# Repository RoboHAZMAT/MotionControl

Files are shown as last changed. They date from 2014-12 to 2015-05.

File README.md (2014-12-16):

Motion Control
=============

Code for the intuitive motion control for the robot. This repo contains all of the code needed to use the wearable motion control interface. Main features are the Motion Control Glove code and the IMU sensor reading programs.

###**Directories:**

  - **HandMotionControlOpt:** An optimized version of the code needed to operate the robot hands using the flex sensor based gloves. Takes the voltage drop readings from the flex sensor in the analog pins and relates that to servo motor rotation angles. Has a calibration method for different sized hands with a default setting as well. Green, yellow, and red LED status lights are used. Written for an Arduino Lilypad.

  - **IMUReading:** Contains several library files developed by Jeff Rowberg to deal with reading in the MPU 9150 IMU sensor we are using as well as the DMP. Two versions of IMU reading programs are functional, one which uses the DMP and one that uses the raw gyroscope and accelerometer data along with our custom Kalman Filter.
  
  - **Kalman Filter MATLAB:** Old code written for Dr. Tomonari Furukawa's Bayesian Robotics course implementing a one DOF Kalman Filter for accurate yaw estimates and drift cancelling.
  
  - **Mechtronic Arm:** In progress directory for controlling the Mechatronic Arm in various ways for testing.
  
  - **Tactile Feedback:** In progress directory used for tactile feedback code. The plan is to use a pressure sensor at the tips of the gripper fingers that senses when the gripper is touching an object. The pressure is related so some sort of tactile feedback method, either small inflatable pressure bags on the glove fingers or small vibration motors. 
  
  - **I2CDev:** Added standard library for communication over I2C on Arduino.

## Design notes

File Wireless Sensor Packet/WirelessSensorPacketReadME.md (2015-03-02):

#Wireless Sensor Packets
In an effort to alleviate cumbersome wires, we are attempting to use the Nordic SemiCondutor nRF24l01+ modules for 2.4Ghz datatransfer. Using the Rf24 library from maniacbug, we communicate with the nRF24l01+ and can send data at rates of up to 2Mbps. SPI protocol is used to configure and communicate with the transceivers. The ultimate goal of this is to have several Wireless Sensor Packets that communicate with IMUs and flex sensors that communicate in a star formation back to a main base node and feed the sensor information into the main Matlab program.

###Wireless Sensor Packet (proposed) Component List
* [Arduino Pro Mini (3.3V, 8MHz) w/ ATMega328] (https://www.sparkfun.com/products/11114)
* [Sparkfun MPU-9150 Breakout Board] (https://www.sparkfun.com/products/11486)
* [Nordic SemiConductor nRF24l01+] (http://www.amazon.com/gp/product/B00E594ZX0/ref=oh_aui_detailpage_o09_s00?ie=UTF8&psc=1) 
* [Polymer Lithium Ion Battery (1000mAh ~ 2000mAh)] (https://www.sparkfun.com/products/339)
* [SparkFun LiPo Charger Basic - Micro-USB] (https://www.sparkfun.com/products/10217)
* [Sparkfun Flex Sensor 4.5"] (https://www.sparkfun.com/products/8606)
* [Button] (https://www.sparkfun.com/products/97)
* [LEDs] (http://www.opel.ece.vt.edu/reference/DataSheets/08LCHR10-LED.pdf)
* [Perfboard] (http://www.dx.com/p/electrical-bakelite-circuit-board-5x7cm-10-piece-132480#.VOuZ5_nF_qs)
* [Switch] (http://www.elexp.com/ProductDetails.aspx?item_no=17SLDH251&CatId=36e69afb-3c1f-4322-9ac3-6e126246b7ae)

#####Variations
There will be two different sensor packets that only vary slightly. Cases are being designed to be 3D printed for each packet set. The packet mounted on the wrist will handle the flex sensor used for actuating the gripper of the robot. This sensors packet will also include 3-4 LEDs. The sensor packet mounted on the bicep of the operator will only have 1-2 LEDs and no flex sensor.

###Testing
To learn how to use the RF24 library, we found an example of a star formation called [starping.pde] (http://maniacbug.github.io/RF24/starping_8pde-example.html) (we copied this into an .ino file). In this setup, the same code can be written to each Arduino participating in the network. The role of the arduino is determined by the status of pin 7. If the value of pin 7 is connected to GND, the arduino behaves as a "pong out" node, which recieves the incoming signals and sends it back to the sender. All other Arduinos behave as "ping" modules which initiate the signal. Each ping module needs an ID. This can be set up in the serial monitor of the Arduino IDE. ID's 2-6 are available to the ping modules, while ID 1 is reserved for the pong back module. An ID of 0 indicates that no ID has been assigned to the node. Once IDs are assigned for a ping module, they are stored in the EEPROM of the Arduino, so they will remain until changed. Slight modification of the starping code is needed for operation on an Arduino Mega due to the specific pin callouts of the SPI functionality on the Mega. Specifically, pin 10 on the Arduino Uno and Pro Mini needs to be changed to pin 53 on the Mega. More information on the setup of the nRF24l01+ can be found on [this website] (http://arduino-info.wikispaces.com/Nrf24L01-2.4GHz-HowTo). It is advisable to solder a 10microF or greater electrolytic capacitor across the VCC and GND pins on the nRF24l01 board, especially when using the Mega. This is due to some issue with the power supplied by the Mega which causes rampant packet loss on the nRF24l01+.

We needed to send data structures instead of just integers like in the starping example. [This example] (http://www.bajdi.com/sending-structs-with-nrf24l01-modules-and-the-rf24-library/) has constructed data structures consisting of both integers and floats. We are combining these examples and mixing in our own code.

###Implementation
We have confirmed the basic example of the starping setup. We successfully sent the IMU data structure (plus more) wirelessly via the Arduino Nano to an Arduino Mega. We are now moving forward with the WSP module (i.e. the housing that will be worn by an operator). An integrated PCB version of the WSP is being worked on which will reduce the size and weight of the WSP.

###PCB Design & Destruction
The PCB we are designing will integrate the major components of the board. The nRF24l01 will remain a separete piece to be soldered into the main board. The breakout boards that we are using are all from Sparkfun. The schematics can be found for each breakout board. We are taking these existing EAGLE schematics and integrating them into one board. In addition to these boards, we need to integrate two LEDs, a slide switch, pin breakouts to connect the nRF24l01, breakout pins for the flex sensor, and a button. There will also need to be debug pads to check voltages on various parts of the board. IMPORTANT: Bootload pins will be needed for the ATMEGA328. [This is a 6-pin configuration TBD] (http://angryelectron.com/how-to-update-the-bootloader-on-arduino-pro-mini-328/). The current iteration is called WSP2.sch. It is still in part selection and integration phase. Schematic integration is almost complete. Breakout pins/debug pads need to be determined. The LEDS and button still need to be connected. Once this is complete, the board needs to be create. It is important that the various pieces be oriented correctly. The MPU 9150 needs to be as close to the edge of the PCB as possible (preferably about 1/4th of the way up the board). This is because the MPU needs to be close to where the wrist will be when worn by an operator. The (indicator) LEDS, button and switch ideally need to be very close to each other to make the controls available on top of the Wireless Sensor packet available,

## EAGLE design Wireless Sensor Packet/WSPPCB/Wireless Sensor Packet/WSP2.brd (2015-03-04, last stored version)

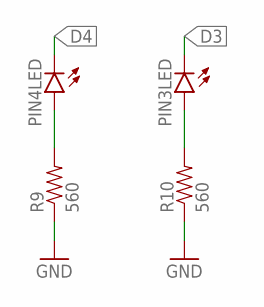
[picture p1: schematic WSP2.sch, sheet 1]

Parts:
PIN3LED, PIN4LED: LED0603; LED-0603
R9, R10: 560; 0603-RES

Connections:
D3: PIN3LED.C; also elsewhere on the board
D4: PIN4LED.C; also elsewhere on the board
GND: R9.1, R10.1; also elsewhere on the board
unnamed: PIN4LED.A, R9.2
unnamed: PIN3LED.A, R10.2

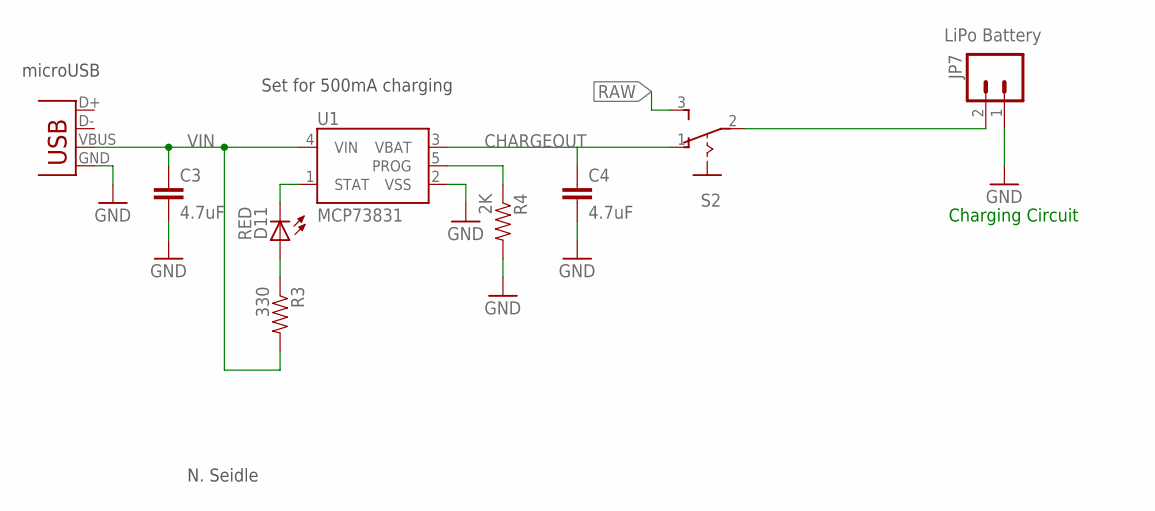
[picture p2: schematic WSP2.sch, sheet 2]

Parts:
C3, C4: 4.7uF; 0402-CAP
D11: RED; LED-0603
JP7: LiPo Battery; JST-2-SMD
R3: 330; 0402-RES
R4: 2K; 0402-RES
S2: 255SB
U1: MCP73831; SOT23-5
X1: Micro USB; USB-MICROB

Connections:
CHARGEOUT: C4.1, S2.1 (O), U1.3 (VBAT)
GND: C3.2, C4.2, JP7.1, R4.2, U1.2 (VSS), X1.GND; also elsewhere on the board
unnamed: D11.A, R3.1
POSBAT: JP7.2, S2.2
PROG: R4.1, U1.5 (PROG)
RAW: S2.3 (S); also elsewhere on the board
STAT: D11.C, U1.1 (STAT)
VIN: C3.1, R3.2, U1.4 (VIN), X1.VBUS

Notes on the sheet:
Set for 500mA charging
N. Seidle
microUSB
Charging Circuit

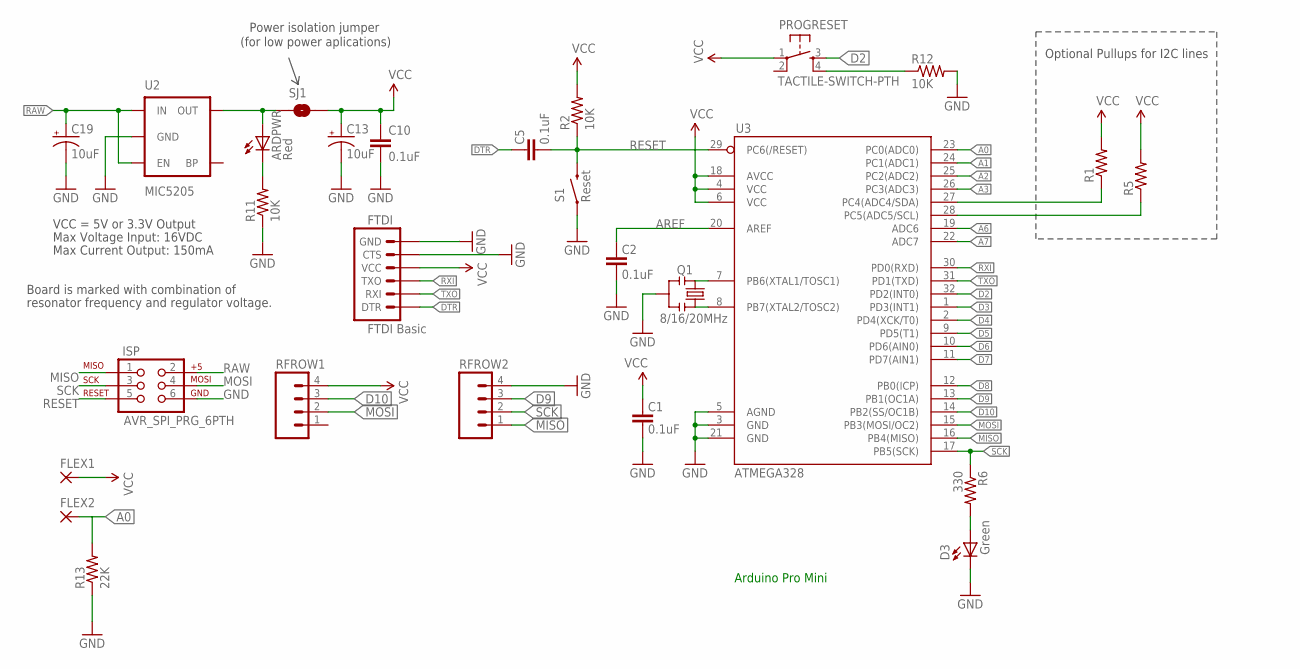
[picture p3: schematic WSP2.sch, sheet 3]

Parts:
ARDPWR: Red; 0603-LED-ALT1
C1, C2, C5, C10: 0.1uF; 0603-CAP
C13, C19: 10uF; EIA3216
D3: Green; 0603-LED-ALT1
FLEX1, FLEX2: 1,6/0,9
FTDI: FTDI Basic; 1X06
ISP: AVR_SPI_PRG_6PTH; 2X3
PROGRESET: TACTILE-SWITCH-PTH; TAC-SWITCH-PTH
Q1: 8/16/20MHz; RESONATOR-SMD-1:1
R1, R5: RESISTOR0603-RES; 0603-RES
R2, R11, R12: 10K; 0603-RES
R6: 330; 0603-RES
R13: 22K; 0603-RES
RFROW1, RFROW2: M041.27MM; 1X04-1.27MM
S1: Reset; TACTILE-SWITCH-SMD-ALT01
SJ1: SOLDERJUMPERNC; SJ_2S
U2: MIC5205; SOT23-5
U3: ATMEGA328; TQFP32-08

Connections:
3.3V: FLEX1.1, FTDI.4 (VCC), PROGRESET.1, RFROW1.4
A0: FLEX2.1, R13.2, U3.23 (PC0(ADC0))
A1: U3.24 (PC1(ADC1))
A2: U3.25 (PC2(ADC2))
A3: U3.26 (PC3(ADC3))
A5: R5.1, U3.28 (PC5(ADC5/SCL))
A6: U3.19 (ADC6)
A7: U3.22 (ADC7)
AREF: C2.2, U3.20 (AREF)
D2: PROGRESET.3, U3.32 (PD2(INT0))
D3: U3.1 (PD3(INT1)); also elsewhere on the board
D4: U3.2 (PD4(XCK/T0)); also elsewhere on the board
D5: U3.9 (PD5(T1))
D6: U3.10 (PD6(AIN0))
D7: U3.11 (PD7(AIN1))
D8: U3.12 (PB0(ICP))
D9: RFROW2.3, U3.13 (PB1(OC1A))
D10: RFROW1.3, U3.14 (PB2(SS/OC1B))
DTR: C5.2, FTDI.1 (DTR)
GND: C1.1, C2.1, C10.2, C13.C (-), C19.C (-), D3.C, FTDI.5 (CTS), FTDI.6 (GND), ISP.6, Q1.2, R11.1, R12.2, R13.1, RFROW2.4, S1.1, S1.2 (1), U2.2 (GND), U3.3 (GND), U3.5 (AGND), U3.21 (GND); also elsewhere on the board
MISO: ISP.1, RFROW2.1, U3.16 (PB4(MISO))
MOSI: ISP.4, RFROW1.2, U3.15 (PB3(MOSI/OC2))
unnamed: Q1.3, U3.8 (PB7(XTAL2/TOSC2))
unnamed: Q1.1, U3.7 (PB6(XTAL1/TOSC1))
unnamed: ARDPWR.A, SJ1.1, U2.5 (OUT)
unnamed: ARDPWR.C, R11.2
unnamed: D3.A, R6.2
unnamed: PROGRESET.4, R12.1
RAW: C19.A (+), ISP.2, U2.1 (IN), U2.3 (EN); also elsewhere on the board
RESET: C5.1, ISP.5, R2.1, S1.3 (2), S1.4 (2), U3.29 (PC6(/RESET))
RXI: FTDI.3 (TXO), U3.30 (PD0(RXD))
SCK: ISP.3, R6.1, RFROW2.2, U3.17 (PB5(SCK))
SDA: R1.1, U3.27 (PC4(ADC4/SDA)); also elsewhere on the board
TXO: FTDI.2 (RXI), U3.31 (PD1(TXD))
VCC: C1.2, C10.1, C13.A (+), R1.2, R2.2, R5.2, SJ1.2, U3.4 (VCC), U3.6 (VCC), U3.18 (AVCC); also elsewhere on the board

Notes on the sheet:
Max Voltage Input: 16VDC
Max Current Output: 150mA
Board is marked with combination of
resonator frequency and regulator voltage.
VCC = 5V or 3.3V Output
Optional Pullups for I2C lines
Power isolation jumper
(for low power aplications)
Arduino Pro Mini

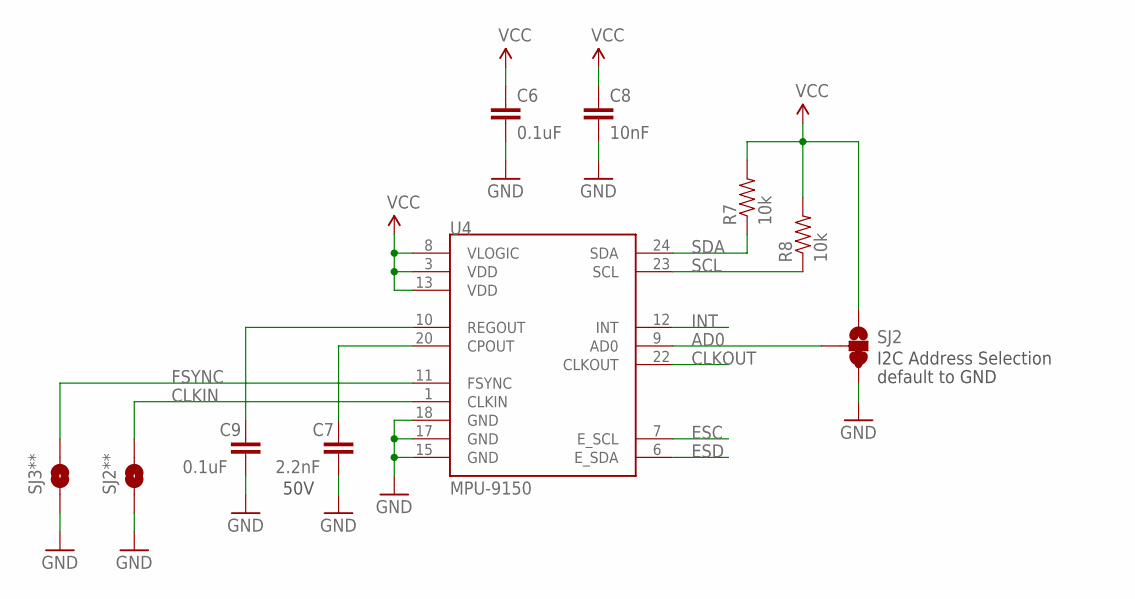
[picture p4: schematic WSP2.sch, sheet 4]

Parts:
C6, C9: 0.1uF; 0402-CAP
C7: 2.2nF; 0402-CAP
C8: 10nF; 0402-CAP
R7, R8: 10k; 0402-RES
SJ2: SOLDERJUMPER_2WAYPASTE2&3; SJ_3_PASTE2&3
SJ2**, SJ3**: SOLDERJUMPERTRACE; SJ_2S-TRACE
U4: MPU-9150; QFN-24-NP

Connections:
AD0: SJ2.2, U4.9 (AD0)
CLKIN: SJ2**.2, U4.1 (CLKIN)
CLKOUT: U4.22 (CLKOUT)
ESC: U4.7 (E_SCL)
ESD: U4.6 (E_SDA)
FSYNC: SJ3**.2, U4.11 (FSYNC)
GND: C6.2, C7.2, C8.2, C9.2, SJ2.3, SJ2**.1, SJ3**.1, U4.15 (GND), U4.17 (GND), U4.18 (GND); also elsewhere on the board
INT: U4.12 (INT)
unnamed: C7.1, U4.20 (CPOUT)
unnamed: C9.1, U4.10 (REGOUT)
SCL: R8.1, U4.23 (SCL)
SDA: R7.1, U4.24 (SDA); also elsewhere on the board
VCC: C6.1, C8.1, R7.2, R8.2, SJ2.1, U4.3 (VDD), U4.8 (VLOGIC), U4.13 (VDD); also elsewhere on the board

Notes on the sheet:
50V
I2C Address Selection
default to GND

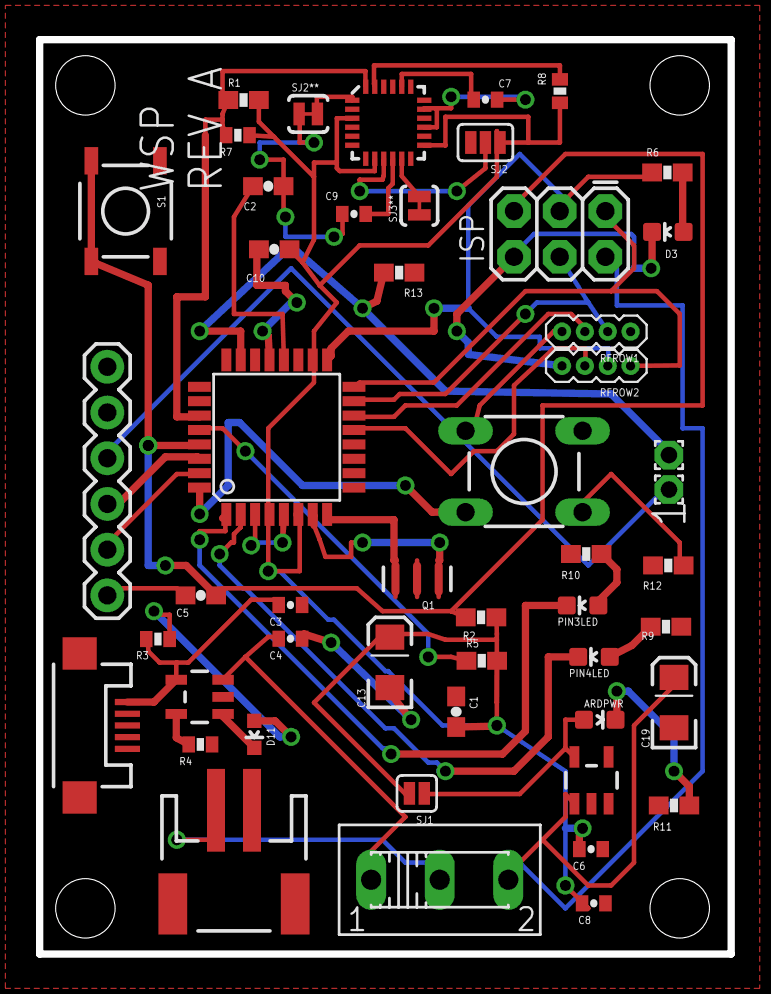
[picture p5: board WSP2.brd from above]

Board: 2 copper layers, 38.4 x 50.8 mm, 54 parts (0 on the bottom side), 40 nets.

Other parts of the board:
JP1, JP2, JP14, JP15: STAND-OFF

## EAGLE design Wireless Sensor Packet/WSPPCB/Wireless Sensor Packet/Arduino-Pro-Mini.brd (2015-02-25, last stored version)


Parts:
C1, C2, C3, C10: 0.1uF; 0603-CAP
C13, C19: 10uF; EIA3216
D3: Green; 0603-LED-ALT1
FRAME1: FRAME-LETTER; CREATIVE_COMMONS
JP1: FTDI Basic; 1X06
JP2, JP3: M02PTH; 1X02
JP5, JP8: FIDUCIALUFIDUCIAL; MICRO-FIDUCIAL
JP6, JP7: M12PTH; 1X12
LED1: Red; 0603-LED-ALT1
Q1: 8/16/20MHz; RESONATOR-SMD-1:1
R1, R3: RESISTOR0603-RES; 0603-RES
R2, R11: 10K; 0603-RES
R6: 330; 0603-RES
S1: Reset; TACTILE-SWITCH-SMD-ALT01
SJ1: SOLDERJUMPERNC; SJ_2S
U1: ATMEGA328; TQFP32-08
U2: MIC5205; SOT23-5
U$1: LOGO-SFESK; SFE-LOGO-FLAME
U$3: OSHW-LOGOS; OSHW-LOGO-S
U$11: LOGO-SFENEW; SFE-NEW-WEBLOGO

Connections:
A0: JP6.8, U1.23 (PC0(ADC0))
A1: JP6.7, U1.24 (PC1(ADC1))
A2: JP6.6, U1.25 (PC2(ADC2))
A3: JP6.5, U1.26 (PC3(ADC3))
A4: JP2.1, R1.1, U1.27 (PC4(ADC4/SDA))
A5: JP2.2, R3.1, U1.28 (PC5(ADC5/SCL))
A6: JP3.1, U1.19 (ADC6)
A7: JP3.2, U1.22 (ADC7)
AREF: C1.2, U1.20 (AREF)
D2: JP7.8, U1.32 (PD2(INT0))
D3: JP7.7, U1.1 (PD3(INT1))
D4: JP7.6, U1.2 (PD4(XCK/T0))
D5: JP7.5, U1.9 (PD5(T1))
D6: JP7.4, U1.10 (PD6(AIN0))
D7: JP7.3, U1.11 (PD7(AIN1))
D8: JP7.2, U1.12 (PB0(ICP))
D9: JP7.1, U1.13 (PB1(OC1A))
D10: JP6.12, U1.14 (PB2(SS/OC1B))
DTR: C2.2, JP1.1 (DTR)
GND: C1.1, C3.1, C10.2, C13.C (-), C19.C (-), D3.C, JP1.5 (CTS), JP1.6 (GND), JP6.2, JP7.9, Q1.2, R11.1, S1.1, S1.2 (1), U1.3 (GND), U1.5 (AGND), U1.21 (GND), U2.2 (GND)
MISO: JP6.10, U1.16 (PB4(MISO))
MOSI: JP6.11, U1.15 (PB3(MOSI/OC2))
unnamed: Q1.3, U1.8 (PB7(XTAL2/TOSC2))
unnamed: Q1.1, U1.7 (PB6(XTAL1/TOSC1))
unnamed: LED1.A, SJ1.1, U2.5 (OUT)
unnamed: LED1.C, R11.2
unnamed: D3.A, R6.2
RAW: C19.A (+), JP6.1, U2.1 (IN), U2.3 (EN)
RESET: C2.1, JP6.3, JP7.10, R2.1, S1.3 (2), S1.4 (2), U1.29 (PC6(/RESET))
RXI: JP1.3 (TXO), JP7.11, U1.30 (PD0(RXD))
SCK: JP6.9, R6.1, U1.17 (PB5(SCK))
TXO: JP1.2 (RXI), JP7.12, U1.31 (PD1(TXD))
VCC: C3.2, C10.1, C13.A (+), JP1.4 (VCC), JP6.4, R1.2, R2.2, R3.2, SJ1.2, U1.4 (VCC), U1.6 (VCC), U1.18 (AVCC)

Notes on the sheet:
Original Arduino Mini Design by Team Arduino
Arduino Pro Mini Design by Spark Fun Electronics
Max Voltage Input: 16VDC
Max Current Output: 150mA
Board is marked with combination of
resonator frequency and regulator voltage.
VCC = 5V or 3.3V Output
Optional Pullups for I2C lines
Off Grid Breakout headers
Power isolation jumper
(for low power aplications)

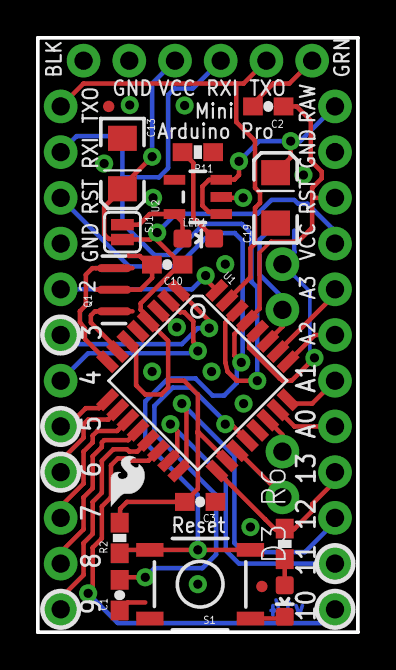
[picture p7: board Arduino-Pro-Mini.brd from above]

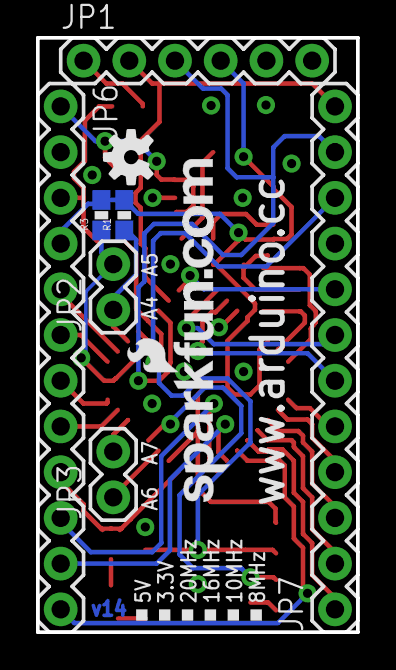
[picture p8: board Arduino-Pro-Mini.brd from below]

Board: 2 copper layers, 17.8 x 33.0 mm, 29 parts (9 on the bottom side), 33 nets.

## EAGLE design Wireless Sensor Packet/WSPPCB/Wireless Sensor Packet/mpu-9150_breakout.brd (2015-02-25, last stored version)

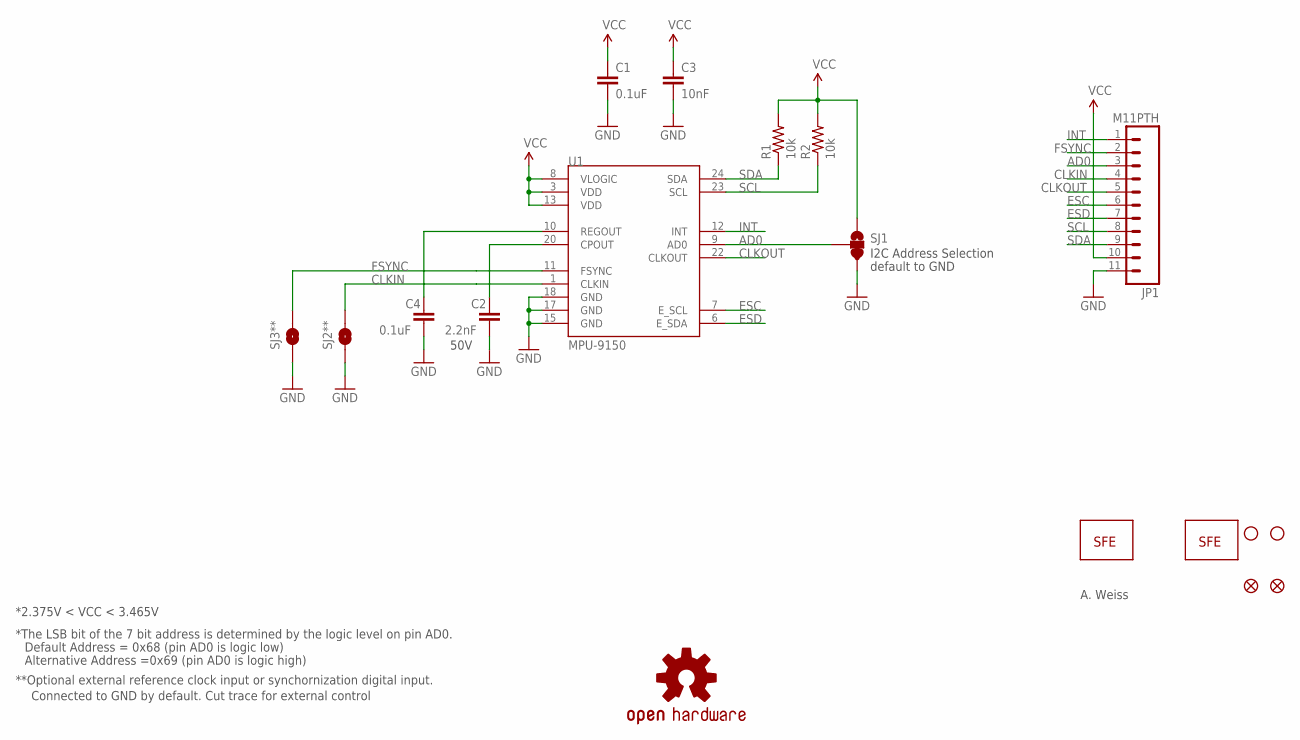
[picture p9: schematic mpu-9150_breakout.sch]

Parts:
C1, C4: 0.1uF; 0402-CAP
C2: 2.2nF; 0402-CAP
C3: 10nF; 0402-CAP
JP1: M11PTH; 1X11
JP2, JP3: STAND-OFF
JP4: LOGO-SFENW2; SFE-NEW-WEB
JP6: LOGO-SFESK; SFE-LOGO-FLAME
JP7, JP8: FIDUCIALUFIDUCIAL; MICRO-FIDUCIAL
R1, R2: 10k; 0402-RES
SJ1: SOLDERJUMPER_2WAYPASTE2&3; SJ_3_PASTE2&3
SJ2**, SJ3**: SOLDERJUMPERTRACE; SJ_2S-TRACE
U1: MPU-9150; QFN-24-NP
U$1: OSHW-LOGOS; OSHW-LOGO-S

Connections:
AD0: JP1.3, SJ1.2, U1.9 (AD0)
CLKIN: JP1.4, SJ2**.2, U1.1 (CLKIN)
CLKOUT: JP1.5, U1.22 (CLKOUT)
ESC: JP1.6, U1.7 (E_SCL)
ESD: JP1.7, U1.6 (E_SDA)
FSYNC: JP1.2, SJ3**.2, U1.11 (FSYNC)
GND: C1.2, C2.2, C3.2, C4.2, JP1.11, SJ1.3, SJ2**.1, SJ3**.1, U1.15 (GND), U1.17 (GND), U1.18 (GND)
INT: JP1.1, U1.12 (INT)
unnamed: C2.1, U1.20 (CPOUT)
unnamed: C4.1, U1.10 (REGOUT)
SCL: JP1.8, R2.1, U1.23 (SCL)
SDA: JP1.9, R1.1, U1.24 (SDA)
VCC: C1.1, C3.1, JP1.10, R1.2, R2.2, SJ1.1, U1.3 (VDD), U1.8 (VLOGIC), U1.13 (VDD)

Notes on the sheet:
50V
I2C Address Selection
**Optional external reference clock input or synchornization digital input.
Connected to GND by default. Cut trace for external control
Default Address = 0x68 (pin AD0 is logic low)
Alternative Address =0x69 (pin AD0 is logic high)
*The LSB bit of the 7 bit address is determined by the logic level on pin AD0.
default to GND
A. Weiss
*2.375V < VCC < 3.465V

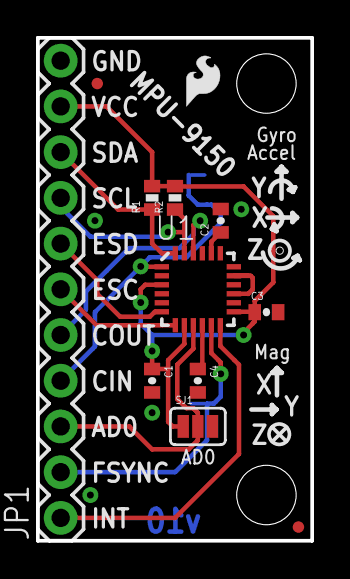
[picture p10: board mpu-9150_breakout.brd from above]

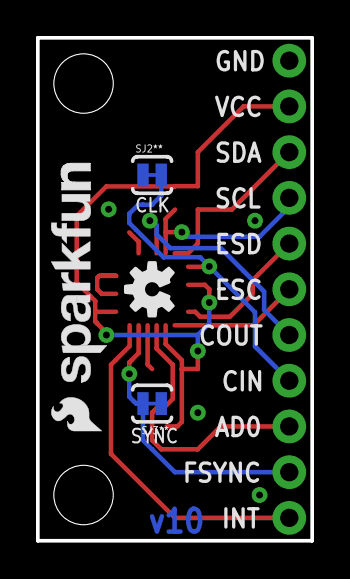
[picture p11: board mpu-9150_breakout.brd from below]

Board: 2 copper layers, 15.2 x 27.9 mm, 19 parts (5 on the bottom side), 13 nets.

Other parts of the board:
JP5: LOGO-SFESK; SFE-LOGO-FLAME

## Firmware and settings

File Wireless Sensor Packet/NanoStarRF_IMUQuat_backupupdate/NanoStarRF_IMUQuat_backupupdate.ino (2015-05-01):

  // ########## Wireless Sensor Packet ##########
/*
John Gardiner & Gerardo Bledt for the 2014-2015 Virginia Tech Mechanical
Engineering Senior Design RoboHazMat Project.
 */

// #### Libraries ####
//From Starping
#include <SPI.h>
#include <EEPROM.h>
#include "nRF24L01.h"
#include "RF24.h"
#include "printf.h"

//from IMU Quat
#include "Wire.h"
#include "I2Cdev.h"
#include "MPU6050_6Axis_MotionApps20.h"

// Set up nRF24L01 radio on SPI bus plus pins 9 & 10
RF24 radio(9,10);

// Instantiate arrays with comm pipes
//const uint64_t talking_pipes[5] = { 0xABCDABCD71LL, 0xF0F0F0F0C3LL, 0xF0F0F0F0B4LL, 0xF0F0F0F0A5LL, 0xF0F0F0F096LL };
//const uint64_t listening_pipes[5] = { 0xABCDABCD71LL, 0x3A3A3A3AC3LL, 0x3A3A3A3AB4LL, 0x3A3A3A3AA5LL, 0x3A3A3A3A96LL };

const uint64_t talking_pipes[5] = { 0xF0F0F0F0D2LL, 0xF0F0F0F0C3LL, 0xF0F0F0F0B4LL, 0xF0F0F0F0A5LL, 0xF0F0F0F096LL };
const uint64_t listening_pipes[5] = { 0x3A3A3A3AD2LL, 0x3A3A3A3AC3LL, 0x3A3A3A3AB4LL, 0x3A3A3A3AA5LL, 0x3A3A3A3A96LL };

// Where in EEPROM is the address stored?
const uint8_t address_at_eeprom_location = 0;

// What is our address (SRAM cache of the address from EEPROM)
// Note that zero is an INVALID address.  The pong back unit takes address
// 1, and the rest are 2-6
uint8_t node_address; //Set the WSP ID Here

// #### Structures ####
// In the future, verification characters need to be added to ensure
// that, even with packet loss, the right numbers are being sent to 
// the right channels.

// Wireless Packet Structure - quaternion and flex sensor
// Since the biceps do not have flex sensors, the will send a 
// specified null value

typedef struct{
  int N; //Sender ID
  float W;// quaternion begin
  float X;
  float Y;
  float Z;// quaternion end
  int F;// Flex sensor
  int reset;
  int T; //Time sent
}
A_t;

//variable declarations
A_t wirelesspacket;

//LEDs
int redled = 6;
int greenled = 7;
int blueled = 8;

//int reset = 0;

//IMU Quat stuff
//============================ Parameter Setup =============================
/* Defines and initializes the MPU9150 IMU sensor, the quaternion object, 
 * the reset button pins, and the MPU control/status variables and buffers.
 */
 
// MPU objeject with 0x68 default I2C address
MPU6050 mpu;

// Initialize Quaternion
Quaternion q;           // [w, x, y, z]

// Reset button pins
const int pinOut = 4; //JRG - Had to change to 1 & 2, 11&13 used by SPI
const int pinIn = 5;

// MPU control / status variables
bool dmpReady = false;  // set true if DMP init was successful
uint8_t devStatus;      // return status after each device operation (0 = success, !0 = error)
uint16_t packetSize;    // expected DMP packet size (default is 42 bytes)
uint16_t fifoCount;     // count of all bytes currently in FIFO
uint8_t fifoBuffer[64]; // FIFO storage buffer

// Flex Sensor Stuff
// Filtering constant 
const int numReadings = 10;
int sensorPin = A0;
int sensorValue = 0;
int maxR;
int minR;
int readingBuffer[numReadings];
int motorPos;
int i = 0;

void setup(void)
{
  // LEDs
  pinMode(6, OUTPUT); //Red
  pinMode(7, OUTPUT); //Green
  pinMode(8, OUTPUT); //Blue

  // Wireless Setup //
  // Read the address from EEPROM
    uint8_t reading = EEPROM.read(address_at_eeprom_location);

    // If it is in a valid range for node addresses, it is the address.
    if ( reading >= 2 && reading <= 6 )
      node_address = reading;

    // Otherwise, it is invalid, so set our address to 0. Readings cannot be sent.
    else
    {
      node_address = 0;
    }

  // Print information
  Serial.begin(115200);
  Serial.print("This is a Wireless Sensor Packet. It's address is: ");
  Serial.println(node_address);

  // Setup and configure rf radio
  radio.begin();
  radio.setDataRate(RF24_2MBPS); // Both endpoints must have this set the same
  radio.setAutoAck(false);       // Either endpoint can set to false to disable ACKs

  // Write on our talking pipe
  radio.openWritingPipe(talking_pipes[node_address-2]);
  // Listen on our listening pipe
  radio.openReadingPipe(1,listening_pipes[node_address-2]);
  
  // Show the details of the radio
  printf_begin();
  radio.printDetails();
  
  //Initializing values - will be sent as confirmation
  wirelesspacket.N = node_address;
  wirelesspacket.W = 1;
  wirelesspacket.X = 2;
  wirelesspacket.Y = 3;
  wirelesspacket.Z = 4;
  wirelesspacket.F = 5;
  
  // ##### IMU Quat #####
  // Begin I2C communication
  Wire.begin();
  
  // Initialize reset button
  //pinMode(pinOut, OUTPUT);
  pinMode(pinIn, INPUT);
  digitalWrite(pinOut, HIGH);

  // Initialize IMU
  Serial.println(F("Initializing I2C devices..."));
  mpu.initialize();
  digitalWrite(redled, HIGH);

  // Load and configure the DMP
  Serial.println(F("Initializing DMP..."));
  devStatus = mpu.dmpInitialize();
  digitalWrite(redled, LOW);
  delay(10);
  //digitalWrite(8, HIGH);
  analogWrite(blueled,220);
  
  // Make sure it worked (returns 0 if so)
  if (devStatus == 0) {
      // Turn on the DMP, now that it's ready
      Serial.println(F("Enabling DMP..."));
      mpu.setDMPEnabled(true);

      // Set our DMP Ready flag so the main loop() function knows it's okay to use it
      dmpReady = true;

      // Get expected DMP packet size for later comparison
      packetSize = mpu.dmpGetFIFOPacketSize();
      
  } else {
      // ERROR!
  }
  // Send confirmation of IMU initialization
  Serial.println("Sending setup confirmation...");
  radio.write( &wirelesspacket, sizeof(wirelesspacket) );
  Serial.println("Sent");
  //digitalWrite(8, LOW);
  analogWrite(blueled,150);
  delay(10);
  //digitalWrite(7, HIGH);
  analogWrite(greenled,150);
  
  //Set Up Flex Sensor Stuff
  maxR = 450;
  minR = 200;
  
  for (int j = 0; j < numReadings; j++) 
  {
    readingBuffer[j] = 0;
  }
  
}

void loop(void)
{
  //Flex Sensors
  int reading;
  reading = constrain(map(analogRead(sensorPin),minR,maxR,175,0),0,175);
  //Serial.println(analogRead(sensorPin)); 
  motorPos = MoveMotor(i,reading,readingBuffer,motorPos);
  //\Serial.println(motorPos);
  
  // IMU Communication // 
  // Resets length
  while (fifoCount < packetSize) fifoCount = mpu.getFIFOCount();
  //Serial.print("FIFO Count Over | ");Serial.println(millis());
  // Get current FIFO count
  fifoCount = mpu.getFIFOCount();

  // Check for overflow (this should never happen unless our code is too inefficient)
  if (fifoCount >= 1024) {
      // Reset so we can continue cleanly
      mpu.resetFIFO();
      //Serial.print("FIFO Reset | ");Serial.println(millis());
  } 
  
  //Serial.print("Start Wait | ");Serial.println(millis());
  // Wait for correct available data length, should be a VERY short wait
  while (fifoCount < packetSize) fifoCount = mpu.getFIFOCount();
  //Serial.print("Finish Wait | ");Serial.println(millis());

  // Read a packet from FIFO
  mpu.getFIFOBytes(fifoBuffer, packetSize);
  //Serial.print("Packet Read | ");Serial.println(millis());
       
  // Track FIFO count here in case there is > 1 packet available
  // (this lets us immediately read more without waiting for an interrupt)
  fifoCount -= packetSize;

  // Display quaternion values in easy matrix form: w x y z
  mpu.dmpGetQuaternion(&q, fifoBuffer);
  //Serial.print("Got Quaternion | ");Serial.println(millis());

  // Reset button status
  int reset = digitalRead(pinIn);
  
  if (reset == HIGH) {     
  // turn LED on:    
  analogWrite(blueled, 150);
  analogWrite(greenled, 0);  
  } 
  else 
  {
   // turn LED off:
   analogWrite(blueled, 0);
   analogWrite(greenled, 150); 
  }
  
  /* Serial debug
  // Creates the communication protocol
  Serial.print("$");
  Serial.print(q.w);Serial.print("#");
  Serial.print(q.x);Serial.print("%");
  Serial.print(q.y);Serial.print("&");
  Serial.print(q.z);Serial.print("@");
  Serial.print(reset);Serial.println("!");
  */
   
  if (node_address != 0){
    // Wireless Comm //
    //Packaging the data into the data structure
    wirelesspacket.N = node_address;
    wirelesspacket.W = q.w;
    wirelesspacket.X = q.x;
    wirelesspacket.Y = q.y;
    wirelesspacket.Z = q.z;
    wirelesspacket.F = motorPos; //Will be changed to analog readn
    wirelesspacket.reset = reset;
    wirelesspacket.T = 0;
    
    //Send the data packet
    //Serial.print("Attempting to Send Packet | "); Serial.println(millis());
    radio.write( &wirelesspacket, sizeof(wirelesspacket) );
    //Serial.print("Packet Sent | ");Serial.println(millis());
  }
  //Setting the address
  if (Serial.available())
  {
    // If the character on serial input is in a valid range...
    char c = Serial.read();
    if ( c >= '1' && c <= '6' )
    {
      // It is our address
      EEPROM.write(address_at_eeprom_location,c-'0');

      // And we are done right now (no easy way to soft reset)
      printf("\n\rManually reset address to: %c\n\rPress RESET to continue!",c);
    }
  }
  
  // Increase the index variable, wrap around the filter constant
  i++;
  if (i >= numReadings) { i = 0; }
  
  // Delay for stability
  delay(1);
  
}

/**
 * Filters the readings for noise by averaging the previous readings for 
 * smooth sensor data.
 * Moves the corresponding sevor motor to the averaged position.
 */
int MoveMotor(int i,int reading,int readingBuffer[],int prevMotorPos) {
  // Calculates the past history
  int totalReading = 0;
  for (int j = 0; j < numReadings; j++) {
    totalReading = totalReading + readingBuffer[j];
  }
  int prevAverage = totalReading / numReadings;
  
  // Wraps around the buffer
  totalReading = totalReading - readingBuffer[i];
  readingBuffer[i] = reading;
  totalReading = totalReading + readingBuffer[i];
  
  // Calculates the filtered reading and translates to Servo degree range
  int motorPos = constrain(totalReading / numReadings,0,175);
  
  // Moves the motors if the new position is more than 2 degrees from the
  // previous motor position
  if (((motorPos - prevMotorPos) > 2) || ((prevMotorPos - motorPos) > 2)) {
    //motor.write(motorPos);
    return motorPos;
  }
  return prevMotorPos;
}

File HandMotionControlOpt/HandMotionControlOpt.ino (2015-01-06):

//========================== Hand Motion Control ===========================
/* RoboHAZMAT Senior Design Team
 * Motion Control Group
 * Gerardo Bledt
 * November 12, 2014
 *
 * Code written for the hand glove motion control glove for the RoboHAZMAT 
 * Senior Design project. Uses flex sensors along each of the fingers to 
 * record the amount of bend for each one and translate that to motion of 
 * the robot fingers by using the Servo motors.
 * 
 * 1. Parameter Setup: Defines and initializes all of the necessary 
 *    variables for the glove.
 *
 * 2. Functions: Contains all of the user created functions to help process
 *    the signals and control the robot.
 *    - Calibrate
 *    - MoveMotor
 *
 * 3. Main Loop: First asks the user to calibrate the flex sensors to their
 *    hand by opening and closing their hand to get the max and min range.
 *    Takes in sensor measurements from the flex sensors and calls the 
 *    function to filter out the signal and then use the filtered value for
 *    the sensor measurement to move the Servo motor position.
 * 
 *    *** TO DO ***
 *     - Optimize code for speed.
 *     - Look at making a generic program for righ and left hand control.
 *     - Documentand comment all code clearly.
 *     - Make a status function for the 3 LEDs. {?}
 *     - Make an LED variable array for easy status definitions.
 *     - Look at naming convention for readings. {?}
 *     - Add thumb sensor for gripping motion.
 */
#include <Servo.h>
 
//============================ Parameter Setup =============================
/* Defines and initializes all of the necessary variables, Servos, sensor
 * pins, and reading buffers. 
 * 
 * Finger Naming Definitions:
 *  - Right thumb  | Left pinky  : [0]
 *  - Right index  | Left ring   : [1]
 *  - Right middle | Left middle : [2]
 *  - Right ring   | Left index  : [3]
 *  - Right pinky  | Left thumb  : [4]
 */

// The indexing variable
int i = 0;   

// Number of flex sensors
const int numSensors = 2;

// Filtering constant 
const int numReadings = 10;   

// Status LEDs
int greenLED = 8;
int yellowLED = 9;
int redLED = 10;

// Serv o motor definitions
Servo motor[numSensors];

// Stores each of the Servo motor positions
int motorPos[numSensors]; 

// Sets up pins for each finger
int pin[numSensors];

// Sets the flex sensor max and mins
int maxR[numSensors];
int minR[numSensors];

// Instantiates reading buffers for filtering
int readingBuffer[numSensors][numReadings];

/**
 * Sets up all of the Servo motors, buffers, and Serial communication.
 */
void setup(){
  // Begins Serial communication
  //Serial.begin(9600);
  
  // Sets up the LEDs
  pinMode(greenLED, OUTPUT);
  pinMode(yellowLED, OUTPUT);
  pinMode(redLED, OUTPUT);
  
  // Red LED lit to show setup ongoing
  digitalWrite(redLED, HIGH);
  
  // Initializes the buffers
  for (int k = 0; k < numSensors; k++) {
    // Sets up the analog pins for sensor readings
    pin[k] = k + 14; // analog pins 14 - 18 (A0 - A4) 
    
    // Attaches the Servo motors to their pins
    motor[k].attach(k + 2);      
    
    // Set up of the min and max values
    maxR[k] = 660;
    minR[k] = 550;
    
    for (int j = 0; j < numReadings; j++) {
      readingBuffer[k][j] = 0;
    }
  }
  delay(1000);
  
  // Calibrates all of the flex sensor max and mins
  Calibrate(); 
}

//=============================== Functions ================================
/* Defines all of the user created functions to be used in the main loop.
 *
 * Functions:
 * - Calibrate
 * - MoveMotor
 */
 
/**
 * Calibrates the flex sensors to find the max and min range for the user.
 */
void Calibrate() {  
  // Delay to give user time
  delay(1000);
  
  // Red off so yellow is on signifying calibration ongoing
  digitalWrite(redLED, LOW);
  digitalWrite(yellowLED, HIGH);

  // Takes 2500 measurements to make sure true values are found
  for (int j = 0; j < 2500; j++) {
    int reading[numSensors]; 
    for (int k = 0; k < numSensors; k++) {
      // Takes reading from each sensor
      reading[k] = analogRead(pin[k]);
    
      // If reading is greater than previous max, it is new max
      // If reading is less than previous min, it is new min
      if (reading[k] > maxR[k]) {maxR[k] = reading[k];} 
      else if (reading[k] < minR[k] || minR[k] < 0) {minR[k] = reading[k];}
    }
    delay(1);
  }
  
  // Green on, red and yellow off to show ready to use
  digitalWrite(greenLED, HIGH);
  digitalWrite(yellowLED, LOW);
}

/**
 * Filters the readings for noise by averaging the previous readings for 
 * smooth sensor data.
 * Moves the corresponding sevor motor to the averaged position.
 */
int MoveMotor(int i,int reading,int readingBuffer[],Servo motor,int prevMotorPos) {
  // Calculates the past history
  int totalReading = 0;
  for (int j = 0; j < numReadings; j++) {
    totalReading = totalReading + readingBuffer[j];
  }
  int prevAverage = totalReading / numReadings;
  
  // Wraps around the buffer
  totalReading = totalReading - readingBuffer[i];
  readingBuffer[i] = reading;
  totalReading = totalReading + readingBuffer[i];
  
  // Calculates the filtered reading and translates to Servo degree range
  int motorPos = constrain(totalReading / numReadings,0,175);
  
  // Moves the motors if the new position is more than 2 degrees from the
  // previous motor position
  if (((motorPos - prevMotorPos) > 2) || ((prevMotorPos - motorPos) > 2)) {
    motor.write(motorPos);
    return motorPos;
  }
  return prevMotorPos;
}

//=============================== Main Loop ================================
/* Main running loop that takes readings for each finger, mapps them and 
 * constrains them within the servo motor's degree range. That reading is 
 * taken and used to move the corresponding Servo motor after being 
 * filtered for noisy signals.
 */
void loop() { 
  // Take the readings from each of the flex sensors on the fingers, map 
  // and constrain them in the Servo motor degree range
  int reading[numSensors];
  for (int k = 0; k < numSensors; k++) {
    reading[k] = constrain(map(analogRead(pin[k]),minR[k],maxR[k],175,0),0,175); 
    motorPos[k] = MoveMotor(i,reading[k],readingBuffer[k],motor[k],motorPos[k]); 
  }
  // Increase the index variable, wrap around the filter constant
  i++;
  if (i >= numReadings) { i = 0; }
  
  // Delay for stability
  delay(1);
}

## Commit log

2014-11-11 Add John's cleaned up mechatronic arm control code.
2014-11-11 Adds the Kalman Filter IMU code and MATLAB <-> Arduino interface.
2014-11-15 Extend range on Servos
2014-11-16 Version Adding and Organizing
    Renamed original Mechatronic_Arm.ino to reflect that it uses only
    Trimpots for control. Added new folders with the newer version that uses
    an Uno and a Mega to control the arm via joysticks. This version has LED
    feedback as well.
2014-11-18 Adds support for reading the IMU
    Uses the standard library for reading raw IMU data for the MPU 9150 for
    on github.
2014-11-18 Increases Servo range limitations.
    Changes the maximum range to open gripper since hardware changes were
    made.
2014-11-18 Adding ability to read IMU.
    Forgot to upload the IMU9_Read.m... Now we can actually read the sensor
    data.
2014-11-19 Custom IMU read program
    UNTESTED.
2014-11-19 Documentation and calibration changes
    Adds commenting on the functions and returns calibration value.
2014-11-24 Working Kalman Filter on the IMU (kinda...)
    The KF works for the IMU in the roll and pitch measurements. Yaw needs
    integration from the magnetometer readings to work. Changed data types
    on some things to make it work.
2014-11-24 Noise removal, data management
    Removes initial measurement noise and also adds smoothing for the
    estimated KF angles. Some commenting and an updated TO TO list.
    [IMU.ino]
2014-11-25 Mechatronic Arm Update
    Uno
    Configured I2C recieve
    May reconfigure as Master
    Meant to read servo positions in array and write to servos
    Mega
    Testing joysticks
    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
2014-11-27 Mechatronic Arm Test
    Commit before changing I2C code majorly
    I2C not working in current configuration
    No read or write is being initiated
    Attempting different configuration after this commit
    [Mechatronic_Arm_Joysticks_Mega.ino, Mechatronic_Arm_Joysticks_Uno.ino]
2014-12-05 Adds good IMU readings with KF and DMP
    No drift and good fusion.
    [HandMotionControlOpt.ino, IMU.ino]
2014-12-16 Changes for use with the arm
    Gets rid of Serial communication (not needed). Adds a default
    calibration in case user forgets to calibrate. Changes LED timings.
    Reverses mapping for servo in arm gripper.
    [HandMotionControlOpt.ino]
2014-12-16 Updated DMP communication
    Allows bug free reading of the IMU DMP data. Gets rid of arm freak outs
    and issues with buffer overflow.
2014-12-16 2 Versions of IMU reading
    Adds 2 different ways to read the IMU data.
    IMUArm uses the DMP
    IMURead uses raw data and a Kalman Filter
2014-12-16 Clean up Mechatronic Arm directory
2014-12-16 Adds John's arm control code
2014-12-25 Adds Quaternion reading support
    Modifies the original IMU code to add support for Quaternion reading and
    output.
2015-01-05 Slows down the rate to avoid saturating the buffer
    [IMUQuat.ino]
2015-01-15 Processing Sketch to Control Mechatronic Arm
2015-02-05 Minor Fix
    Method names were incorrect and thus not being recognized by Arduino
    compiler. Removed "TC" at the end of the method names. Now properly
    compiles. Testing needed to confirm that change is correct & that the
    IMU reads properly.
2015-02-20 Wireless Sensor Packet Initial Commit
    Included is the RF24 library with all necessary files for using the
    nrf24l01+ RF transceivers. The included .ino's are configured for three
    different Arduino boards.
2015-02-20 Wireless Sensor Packet ReadME initial Commit
2015-02-24 Wireless Quaternion Transmit Working
    -Combined and altered many pieces of code
    -Mega serves as receiver in testing
    -Uno was used to test new data structure
    -Nano with IMU transmitted actual readings to Mega successfully
    -Refinement needed to make as smooth, clear and fast as possible at this
    level.
2015-02-25 Wireless Sensor Packet PCB
    Initial Commit
    [Arduino-Pro-Mini.brd, Arduino-Pro-Mini.sch, LiPo-Charger-Basic-v10.brd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]
2015-03-02 WSPPCB2
    Updated main file, renamed to WSP2.
    [Arduino-Pro-Mini.brd, LiPo-Charger-Basic-v10.brd, WSP2.brd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]
2015-03-02 WSPPCB Update
    Created initial component layout for PCB
    [WSP2.brd, WSP2.sch]
2015-03-04 Rev A of WSP PCB
    [WSP2.brd, WSP2.sch]
2015-03-23 Good things
    -MX64T arbotix-m code
    -cleaned up wireless IMU stuff
    -added intialization checks
2015-04-01 Tested and bug removal
    [MX_64_Control_Arbotix.ino, MegaStarRF.ino, NanoStarRF_IMUQuat.ino]
2015-04-16 Just to be safe update
    -Added altered ax12 libraries with new added functions
    -added mx64 arbotix code with setup loop for initializing mx64
    paramters, remove serial debug lines
    -added debug version of pro mini WSP code
    -Changed MegaStarRF to work with Uno, removed debug lines
    -Re-added serial interface for WSP Code to change address
    [Arduino-Pro-Mini.sch, LiPo-Charger-Basic-v10.sch, WSP2.brd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]
2015-04-20 Minor Updates
    -Addition of debug copies
    -fixed pipes setup (set back to original array)
    -Added/fixed button press reset
    [NanoStarRF_IMUQuat.ino]
2015-04-24 Improvements
    Arbotix Code
    -changed serial so that it might actually work
    -changed feed string to "00!0000" thanks to simplifications
    -uses custom ax12 library, be sure to get one with LED and EEProm lock
    added
    MegaStarRF
    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

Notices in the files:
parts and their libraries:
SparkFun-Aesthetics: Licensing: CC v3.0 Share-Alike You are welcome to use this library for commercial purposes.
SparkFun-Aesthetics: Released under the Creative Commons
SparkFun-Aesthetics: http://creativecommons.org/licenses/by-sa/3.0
